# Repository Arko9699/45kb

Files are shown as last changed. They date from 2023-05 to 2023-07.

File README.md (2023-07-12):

# ark40
A simple 40% keyboard with an HHKB-like layout. Two-piece case with gasket mounting, inspired by the flurpes' C-13X.

# Layout
layout

# Renders
front
back
side

# Features
* HHKB-like layout
* Gasket mount
* Unified Daughterboard
* QMK Firmware (WIP)
* Made using KiCad 7.0.5

# Specs
* Front Height : 19mm
* Dimensions : 285.2mm x 92mm x 26.9mm
* Typing Angle : 4.5 degree
* Case Material : Aluminium 6061
* Case Weight : 782g
* Gaskets : 8x rounded 60mm x 4mm x 3mm gasket strips (compatible with D65 gasket strips on KBDFans)
# NOTE
There is an case bottom that is meant to be used with a Waveshare RP2040 Zero for a handwired build. Make sure to use the correct plate file with plate mount stabilisers cutouts.

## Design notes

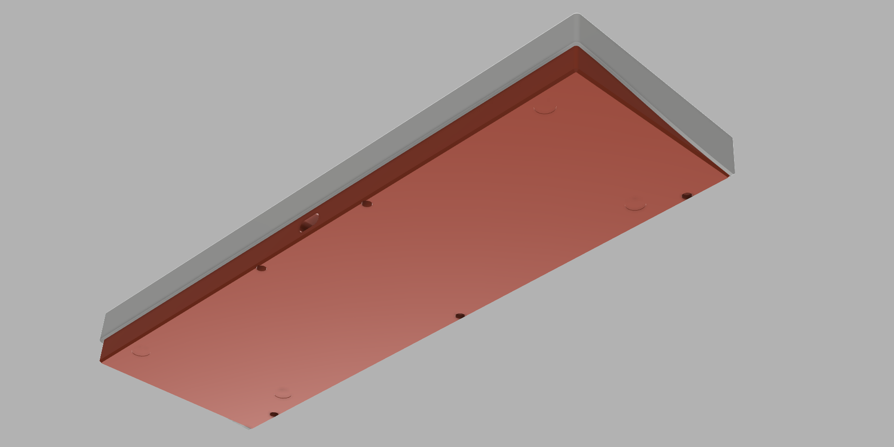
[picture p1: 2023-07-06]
pics/butt.png

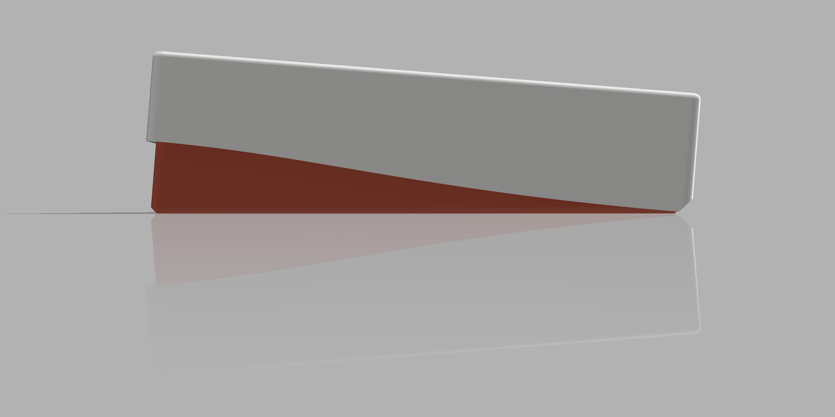
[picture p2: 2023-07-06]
pics/ark40_side.png

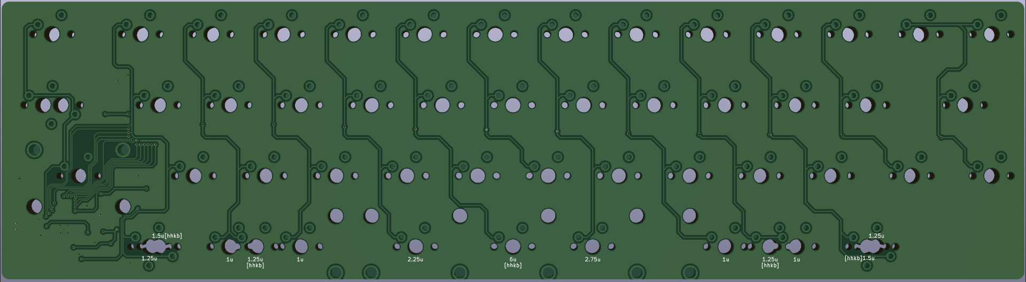
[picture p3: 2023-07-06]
pics/pcb_front.png

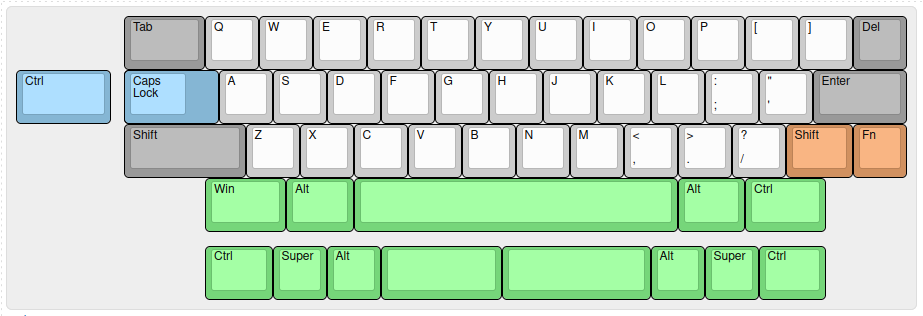
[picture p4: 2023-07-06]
pics/layout.png

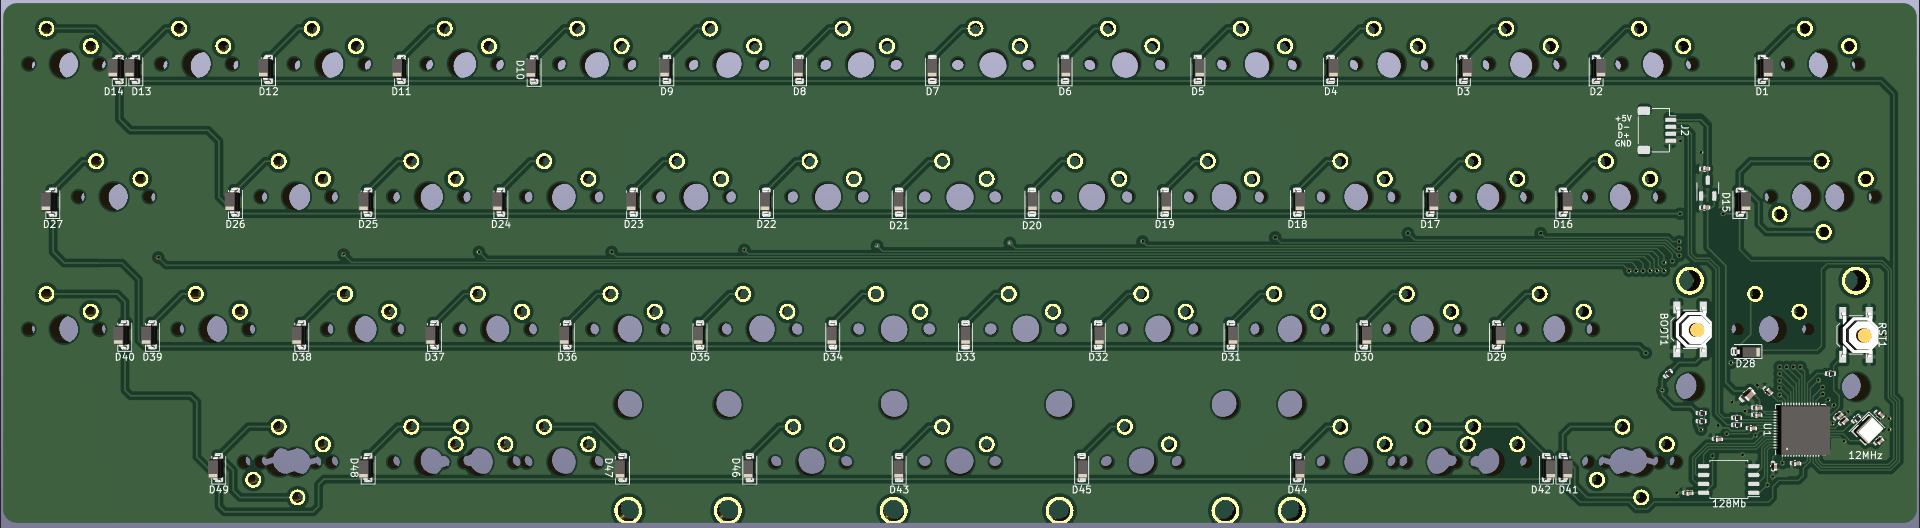
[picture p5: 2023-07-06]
pics/pcb_back.png

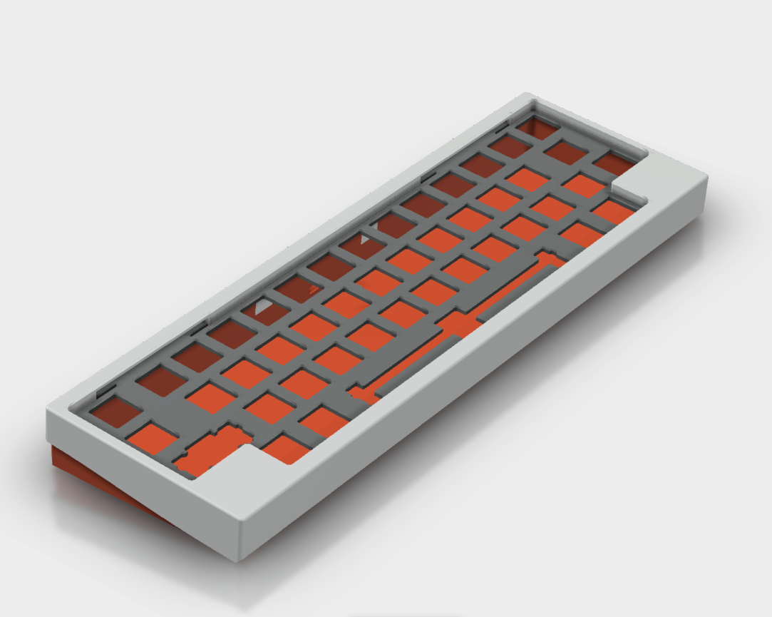
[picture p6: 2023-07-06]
pics/front.png

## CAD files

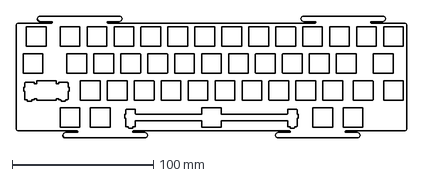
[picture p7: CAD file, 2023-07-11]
hw_plate.dxf
276.2 x 86.2 mm

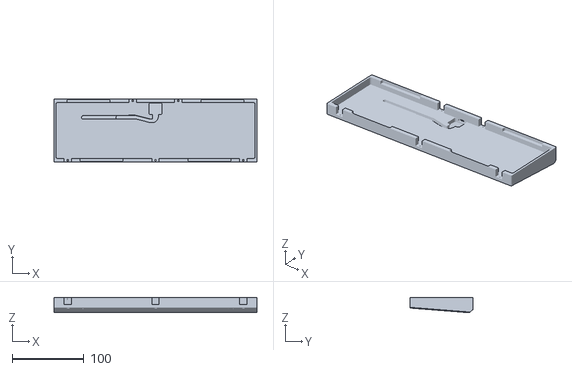
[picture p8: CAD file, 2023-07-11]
stl/bottom[uDB].stl
282.2 x 88.2 x 21.5

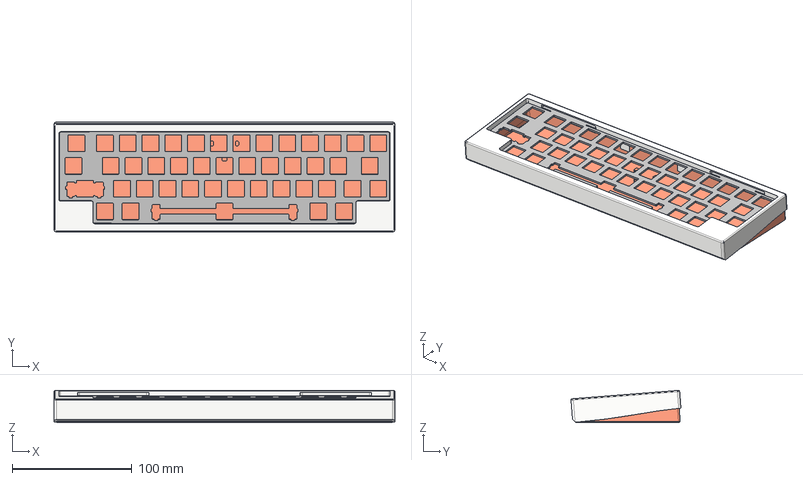
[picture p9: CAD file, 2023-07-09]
ark40.step
285.2 x 92.0 x 26.9 mm
top
bottom
plate

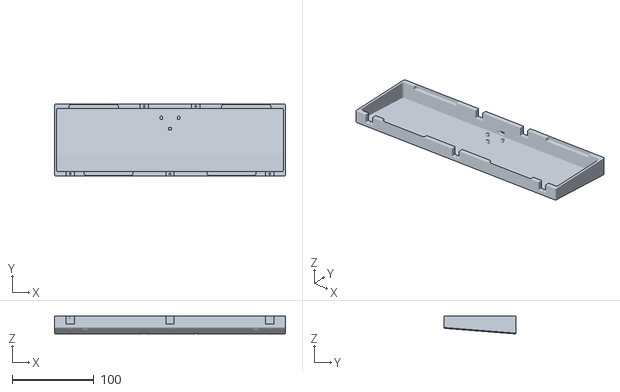
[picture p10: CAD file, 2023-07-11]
stl/bottom[rp2040z].stl
282.2 x 88.2 x 21.9

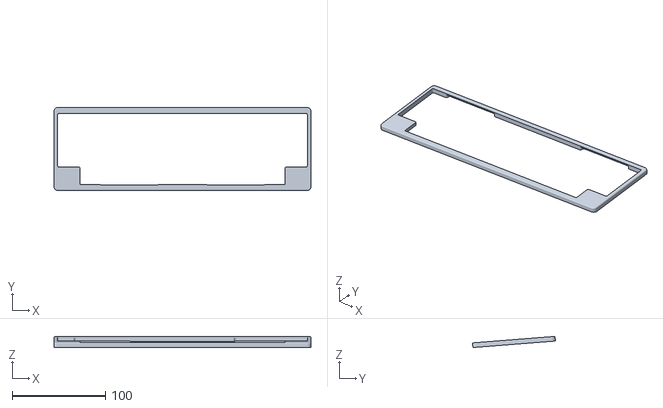
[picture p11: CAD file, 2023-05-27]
stl/top.stl
275.2 x 88.7 x 11.9

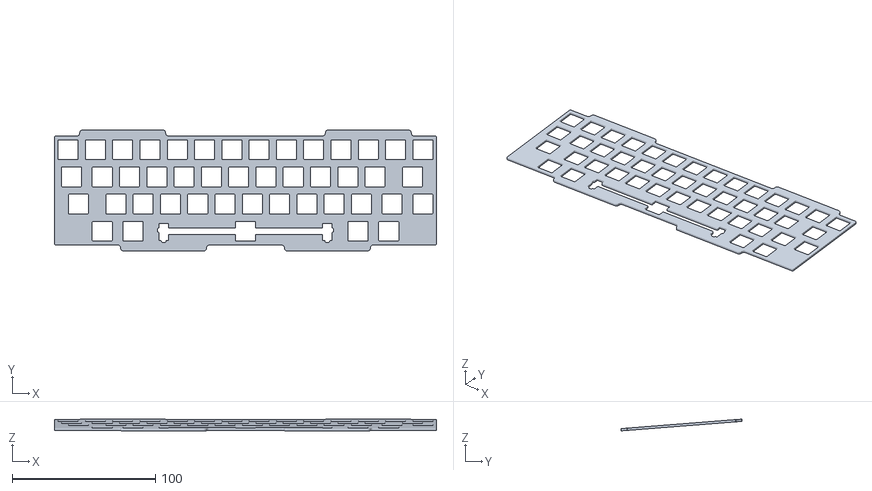
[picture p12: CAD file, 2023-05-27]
stl/plate.stl
266.7 x 84.6 x 8.24

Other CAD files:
plate.dxf

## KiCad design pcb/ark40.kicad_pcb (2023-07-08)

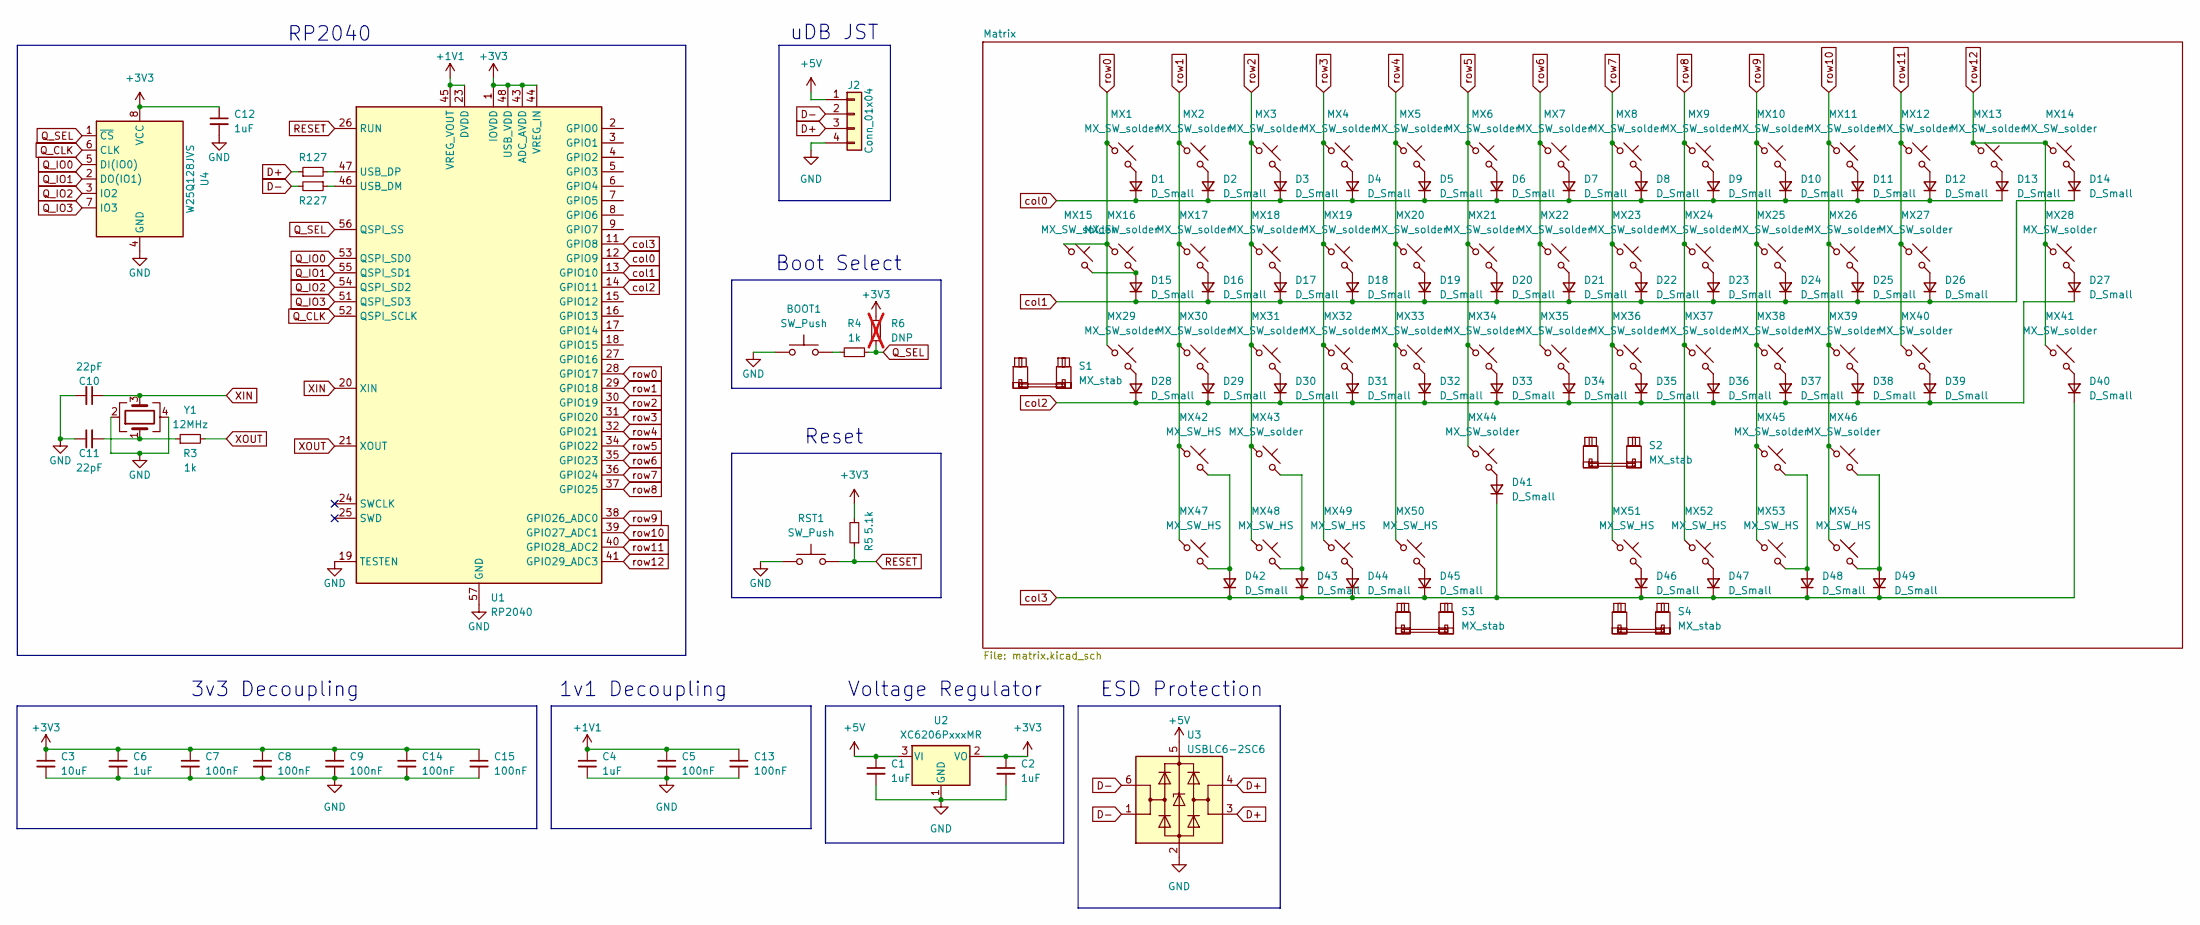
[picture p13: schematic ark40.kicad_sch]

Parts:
BOOT1: SW_Push; SW_SPST_TL3342; LCSC C318884
C1, C2, C4, C6, C12: 1uF; C_0402_1005Metric; LCSC C52923
C3: 10uF; C_0603_1608Metric; LCSC C19702
C5, C7, C8, C9, C13, C14, C15: 100nF; C_0402_1005Metric; LCSC C1525
C10, C11: 22pF; C_0402_1005Metric; LCSC C1555
D1, D2, D3, D4, D5, D6, D7, D8, D9, D10, D11, D12, D13, D14, D15, D16, D17, D18, D19, D20, D21, D22, D23, D24, D25, D26, D27, D28, D29, D30, D31, D32, D33, D34, D35, D36, D37, D38, D39, D40, D41, D42, D43, D44, D45, D46, D47, D48, D49: D_Small; D_SOD-123; LCSC C81598
J2: Conn_01x04; JST_SH_SM04B-SRSS-TB_1x04-1MP_P1.00mm_Horizontal; LCSC C160390
MX1, MX46: MX_SW_solder; SW_MX_1.5u
MX2, MX3, MX4, MX5, MX6, MX7, MX8, MX9, MX10, MX11, MX12, MX13, MX14, MX17, MX18, MX19, MX20, MX21, MX22, MX23, MX24, MX25, MX26, MX27, MX29, MX30, MX31, MX32, MX33, MX34, MX35, MX36, MX37, MX38, MX39, MX41, MX44: MX_SW_solder; SW_MX_1u
MX15, MX28: MX_SW_solder; SW_MX_1.75u
MX16: MX_SW_solder; SW_MX_1.75u_STP_1.25
MX40, MX43, MX45: MX_SW_solder; SW_MX_1.25u
MX42: MX_SW_HS; SW_MX_1.5u
MX47, MX54: MX_SW_HS; SW_MX_1.25u
MX48, MX49, MX50, MX51, MX52, MX53: MX_SW_HS; SW_MX_1u
R1, R2: 27; R_0402_1005Metric; LCSC C140174
R3, R4: 1k; R_0402_1005Metric; LCSC C11702
R5: 5.1k; R_0402_1005Metric; LCSC C25905
R6: DNP; R_0402_1005Metric; LCSC C279981; not fitted
RST1: SW_Push; SW_SPST_TL3342; LCSC C318884
S1, S3: MX_stab; STAB_MX_P_2.25u
S2: MX_stab; STAB_MX_P_6u
S4: MX_stab; STAB_MX_P_2.75u
U1: RP2040; QFN-56-1EP_7x7mm_P0.4mm_EP3.2x3.2mm; LCSC C2040
U2: XC6206PxxxMR; SOT-23-3; LCSC C5446
U3: USBLC6-2SC6; SOT-23-6; LCSC C2687116
U4: W25Q128JVS; SOIC-8_5.23x5.23mm_P1.27mm; LCSC C97521
Y1: 12MHz; Crystal_SMD_3225-4Pin_3.2x2.5mm; LCSC C9002

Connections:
+1V1: C4.1, C5.1, C13.1, U1.23 (DVDD), U1.45 (VREG_VOUT), U1.50 (DVDD)
+3V3: C2.1, C3.1, C6.1, C7.1, C8.1, C9.1, C12.1, C14.1, C15.1, R5.2, R6.2, U1.1 (IOVDD), U1.10 (IOVDD), U1.22 (IOVDD), U1.33 (IOVDD), U1.42 (IOVDD), U1.43 (ADC_AVDD), U1.44 (VREG_IN), U1.48 (USB_VDD), U1.49 (IOVDD), U2.2 (VO), U4.8 (VCC)
+5V: C1.1, J2.1, U2.3 (VI), U3.5 (VBUS)
D+: J2.3, R1.1, U3.3 (I/O2), U3.4 (I/O2)
D-: J2.2, R2.2, U3.1 (I/O1), U3.6 (I/O1)
GND: BOOT1.1, C1.2, C2.2, C3.2, C4.2, C5.2, C6.2, C7.2, C8.2, C9.2, C10.2, C11.1, C12.2, C13.2, C14.2, C15.2, J2.4, RST1.1, U1.19 (TESTEN), U1.57 (GND), U2.1 (GND), U3.2 (GND), U4.4 (GND), Y1.2, Y1.4
unnamed: BOOT1.2, R4.1
unnamed: C11.2, R3.1, Y1.1
unnamed: D1.2 (A), MX1.2
unnamed: D2.2 (A), MX2.2
unnamed: D3.2 (A), MX3.2
unnamed: D4.2 (A), MX4.2
unnamed: D5.2 (A), MX5.2
unnamed: D6.2 (A), MX6.2
unnamed: D7.2 (A), MX7.2
unnamed: D8.2 (A), MX8.2
unnamed: D9.2 (A), MX9.2
unnamed: D10.2 (A), MX10.2
unnamed: D11.2 (A), MX11.2
unnamed: D12.2 (A), MX12.2
unnamed: D13.2 (A), MX13.2
unnamed: D14.2 (A), MX14.2
unnamed: D15.2 (A), MX15.2, MX16.2
unnamed: D16.2 (A), MX17.2
unnamed: D17.2 (A), MX18.2
unnamed: D18.2 (A), MX19.2
unnamed: D19.2 (A), MX20.2
unnamed: D20.2 (A), MX21.2
unnamed: D21.2 (A), MX22.2
unnamed: D22.2 (A), MX23.2
unnamed: D23.2 (A), MX24.2
unnamed: D24.2 (A), MX25.2
unnamed: D25.2 (A), MX26.2
unnamed: D26.2 (A), MX27.2
unnamed: D27.2 (A), MX28.2
unnamed: D28.2 (A), MX29.2
unnamed: D29.2 (A), MX30.2
unnamed: D30.2 (A), MX31.2
unnamed: D31.2 (A), MX32.2
unnamed: D32.2 (A), MX33.2
unnamed: D33.2 (A), MX34.2
unnamed: D34.2 (A), MX35.2
unnamed: D35.2 (A), MX36.2
unnamed: D36.2 (A), MX37.2
unnamed: D37.2 (A), MX38.2
unnamed: D38.2 (A), MX39.2
unnamed: D39.2 (A), MX40.2
unnamed: D40.2 (A), MX41.2
unnamed: D41.2 (A), MX44.2
unnamed: D42.2 (A), MX42.2, MX47.2
unnamed: D43.2 (A), MX43.2, MX48.2
unnamed: D44.2 (A), MX49.2
unnamed: D45.2 (A), MX50.2
unnamed: D46.2 (A), MX51.2
unnamed: D47.2 (A), MX52.2
unnamed: D48.2 (A), MX45.2, MX53.2
unnamed: D49.2 (A), MX46.2, MX54.2
unnamed: R2.1, U1.46 (USB_DM)
unnamed: R1.2, U1.47 (USB_DP)
Q_CLK: U1.52 (QSPI_SCLK), U4.6 (CLK)
Q_IO0: U1.53 (QSPI_SD0), U4.5 (DI(IO0))
Q_IO1: U1.55 (QSPI_SD1), U4.2 (DO(IO1))
Q_IO2: U1.54 (QSPI_SD2), U4.3 (IO2)
Q_IO3: U1.51 (QSPI_SD3), U4.7 (IO3)
Q_SEL: R4.2, R6.1, U1.56 (QSPI_SS), U4.1 (~CS)
RESET: R5.1, RST1.2, U1.26 (RUN)
XIN: C10.1, U1.20 (XIN), Y1.3
XOUT: R3.2, U1.21 (XOUT)
col0: D1.1 (K), D2.1 (K), D3.1 (K), D4.1 (K), D5.1 (K), D6.1 (K), D7.1 (K), D8.1 (K), D9.1 (K), D10.1 (K), D11.1 (K), D12.1 (K), D13.1 (K), U1.12 (GPIO9)
col1: D14.1 (K), D15.1 (K), D16.1 (K), D17.1 (K), D18.1 (K), D19.1 (K), D20.1 (K), D21.1 (K), D22.1 (K), D23.1 (K), D24.1 (K), D25.1 (K), D26.1 (K), U1.13 (GPIO10)
col2: D27.1 (K), D28.1 (K), D29.1 (K), D30.1 (K), D31.1 (K), D32.1 (K), D33.1 (K), D34.1 (K), D35.1 (K), D36.1 (K), D37.1 (K), D38.1 (K), D39.1 (K), U1.14 (GPIO11)
col3: D40.1 (K), D41.1 (K), D42.1 (K), D43.1 (K), D44.1 (K), D45.1 (K), D46.1 (K), D47.1 (K), D48.1 (K), D49.1 (K), U1.11 (GPIO8)
row0: MX1.1, MX15.1, MX16.1, MX29.1, U1.28 (GPIO17)
row1: MX2.1, MX17.1, MX30.1, MX42.1, MX47.1, U1.29 (GPIO18)
row2: MX3.1, MX18.1, MX31.1, MX43.1, MX48.1, U1.30 (GPIO19)
row3: MX4.1, MX19.1, MX32.1, MX49.1, U1.31 (GPIO20)
row4: MX5.1, MX20.1, MX33.1, MX50.1, U1.32 (GPIO21)
row5: MX6.1, MX21.1, MX34.1, MX44.1, U1.34 (GPIO22)
row6: MX7.1, MX22.1, MX35.1, U1.35 (GPIO23)
row7: MX8.1, MX23.1, MX36.1, MX51.1, U1.36 (GPIO24)
row8: MX9.1, MX24.1, MX37.1, MX52.1, U1.37 (GPIO25)
row9: MX10.1, MX25.1, MX38.1, MX45.1, MX53.1, U1.38 (GPIO26_ADC0)
row10: MX11.1, MX26.1, MX39.1, MX46.1, MX54.1, U1.39 (GPIO27_ADC1)
row11: MX12.1, MX27.1, MX40.1, U1.40 (GPIO28_ADC2)
row12: MX13.1, MX14.1, MX28.1, MX41.1, U1.41 (GPIO29_ADC3)

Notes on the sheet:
uDB JST
1v1 Decoupling
Reset
3v3 Decoupling
Boot Select
RP2040
Voltage Regulator
ESD Protection

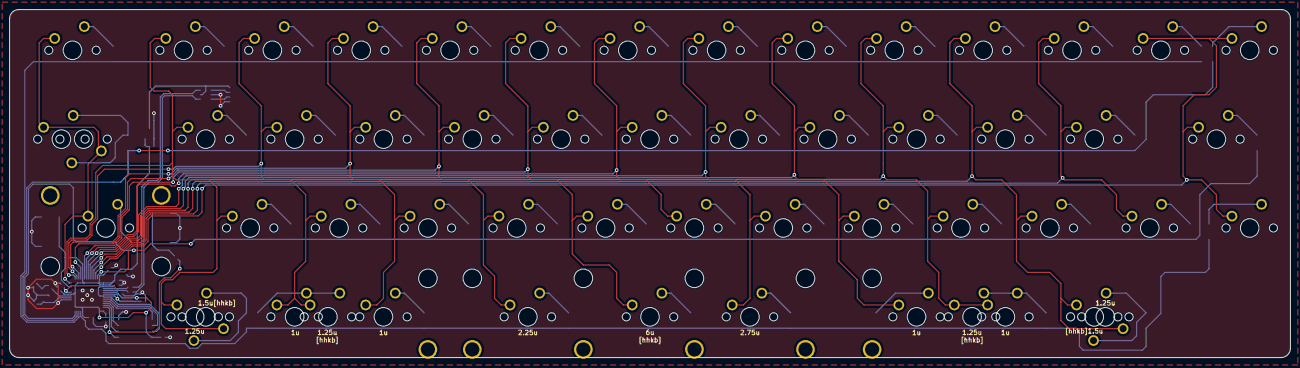
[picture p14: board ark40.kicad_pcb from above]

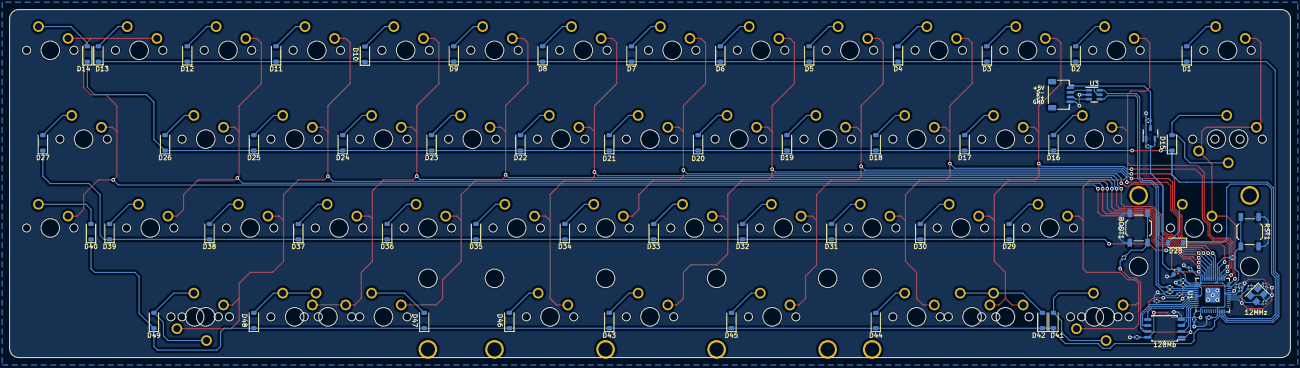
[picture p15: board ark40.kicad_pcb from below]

Board: 2 copper layers, 274.6 x 74.6 mm, 135 parts (77 on the bottom side), 85 nets.
